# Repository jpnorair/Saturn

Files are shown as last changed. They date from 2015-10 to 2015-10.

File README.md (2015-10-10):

About Saturn I
==============
Saturn I is a board for prototyping low power wireless solutions using OpenTag/DASH7.  It can be used for other purposes as well, but it has a set of features optimized for low-power wireless systems.

Important URLs
==============
 * [Saturn Repository](http://www.github.com/jpnorair/saturn)
 * [OpenTag Repository](http://www.github.com/jpnorair/opentag)
 * [Saturn Wiki on Indigresso](http://www.indigresso.com/wiki/doku.php?id=opentag:board:haystack-saturn-i)
 * [Public Forum on Indigresso](http://www.indigresso.com/forum/)
 * [Pro Support by Haystack](http://www.haystacktechnologies.com)

Licensing
=========
Saturn I is licensed via the GPLv3.  The schematics and board design files are done in DipTrace, and they are available on GitHub.  OpenTag firmware supports the Saturn I, which is also available on GitHub.  Parties interested in a non-GPL version of the Saturn-I design should contact JP Norair to discuss licensing terms.

Building Saturn I Boards
========================
If you decide to build your own Saturn-I boards and resell them, contact JP Norair in order to get a link to your storefront posted on this page.

Otherwise, you can get Saturn-I boards fully produced, on-demand, by [Tempo Automation](http://www.tempoautomation.com).  Tempo has the design on file and is ready to go, just tell them how many you need.  If you want to stuff your own boards and save money (at the expense of time and frustration), there's a ZIP package in the repository ready to go to [OSHPark](http://www.oshpark.com), as well as the necessary assembly files, drawings, and stencil gerbers.  Saturn-I is not designed to be assembled by hobbyists, so be forewarned, as it uses some very small surface mount components.

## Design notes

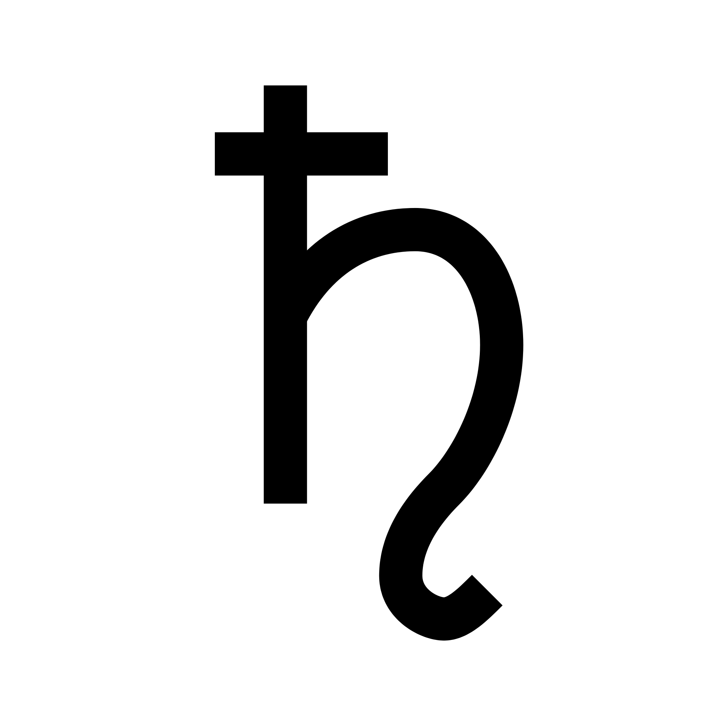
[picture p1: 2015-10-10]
Saturn-I/images/2000px-Saturn_symbol.svg.png

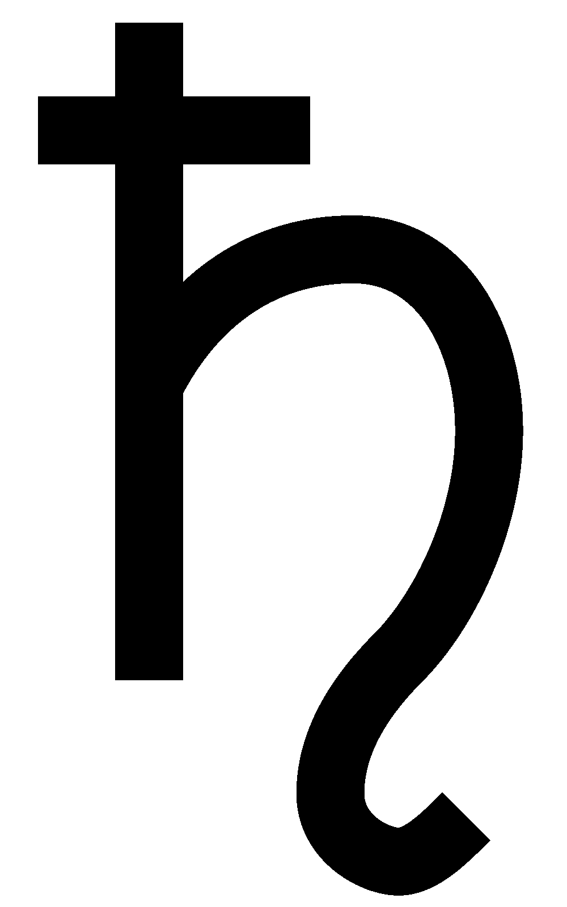
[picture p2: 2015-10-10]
Saturn-I/images/1600px-Saturn_symbol.bmp

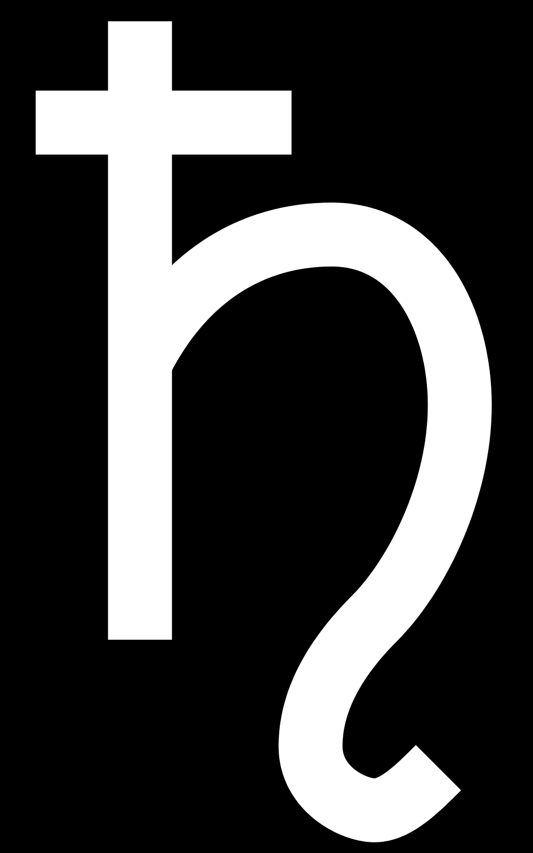
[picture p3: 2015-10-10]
Saturn-I/images/1600px-Saturn_symbol_.png

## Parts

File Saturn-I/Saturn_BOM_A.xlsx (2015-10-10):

Drawing Type | BILL OF MATERIALS
Drawing Title | Saturn I 915 BOM
Revision | 0
Engineer | JP Norair
Release date | 2015-06-15
item | Rev | qty | mfg | part number | alt part number | description (wide tolerance) | references | Comments
1 | 0 | 1 | STMicro | SPIRIT1QTR |  | RF IC | U2
2 | 0 | 1 | STMicro | STM32L151CCU6 |  | MCU, 7x7x0.5 mm | U1
3 | 0 | 1 | STMicro | USBLC6-2P6 |  | SOT-6 USB Protect Diode IC | U3
4 |  | 1 | NXP | NX3L1T384 |  | Leadless Analog Switch | U5
5 |  | 1 | TI | TPS780330220DRV |  | SOT-6 Linear Regulator, 3.3V/2.2V | U4
6 | 0 | 1 | TI | TPS735 |  | SOT-6 Linear Regulator, 3.3V | U6
7 |  | 3 | Panasonic | DB2S20500L |  | SOD-523 (SSMini2) Schottky Diode, If = 200mA | D1, D2, D3
8 |  | 1 | Rohm | SML-P11DTT86 |  | 0402 Orange LED | D4
9 |  | 1 | Rohm | SML-P11MTT86 |  | 0402 Green LED | D5
10 |  | 4 | NXP | BZX884-B5V1,315 |  | SOD-882 Zener Diode, 5.1V | D6, D7, D8, D9
11
12 | 0 | 3 | Murata | GRM155R60J475ME47D |  | 0402 4.7uF X5R decoupling cap | C0, C8, C41
13 | 0 | 9 | Murata | GRM155R71C104KA88D |  | 0402 100nF X7R decoupling cap | C1, C2, C3, C4, C10, C11, C20, C32, C38
14 | 0 | 5 | Murata | GRM155R61A105KE15D |  | 0402 1uF X5R decoupling cap | C5, C9, C31, C39, C40
15 | 0 | 4 | Murata | GRM1555C1H100JA01D |  | 0402 10pF C0G/NP0 crystal caps | C6, C7, C29, C30
16 | 0 | 1 | Murata | GJM1555C1H7R0CB01D |  | 0402 7pF C0G/NP0 RF cap | C21
17 | 0 | 1 | Murata | GJM1555C1H2R4BB01D |  | 0402 2.4pF C0G/NP0 RF cap | C22
18 | 0 | 1 | Murata | GJM1555C1H3R6BB01D |  | 0402 3.6pF C0G/NP0 RF cap | C23
19 | 0 | 1 | Murata | GJM1555C1H2R2BB01D |  | 0402 2.2pF C0G/NP0 RF cap | C24
20 | 0 | 1 | Murata | GJM1555C1H1R5BB01D |  | 0402 1.5pF C0G/NP0 RF cap | C25
21 | 0 | 1 | Murata | GRM1555C1H331JA01D |  | 0402 330pF C0G/NP0 DC blocking cap | C26, C33
22 | 0 | 2 | Murata | GRM1555C1H221JA01D |  | 0402 220pF C0G/NP0 DC blocking cap | C27, C28
23 | 0 | 3 | Murata | GRM1555C1H331JA01D |  | 0402 330pF C0G/NP0 decoupling cap | C33, C37
24 | 0 | 2 | N/A | N/A |  | 0402 No Stuff | C34, C35 | No Stuff
25 | 0 | 2 | Murata | GRM155R71E103KA01D |  | 0402 10nF X7F decoupling cap | C36, C42
26 | 0 | 1 | Murata | LQG15HSR10J02D |  | 0402 100nH inductor | L20
27 | 0 | 1 | Murata | LQG15HS3N6S02D |  | 0402 3.6 nH RF inductor | L21
28 | 0 | 1 | Murata | LQG15HS5N1S02D |  | 0402 5.1 nH RF inductor | L22
29 | 0 | 1 | Panasonic | ERJ-2GE0R00X |  | 0402 Jumper | L23
30 | 0 | 1 | Murata | LQG15HS15NJ02D |  | 0402 15 nH RF inductor | L24, L26
31 | 0 | 1 | Murata | LQG15HS18NJ02D |  | 0402 18 nH RF inductor | L25
32 | 0 | 1 | Murata | LQM21FN100M80L |  | 0805 10uH shielded power inductor | L27
33 | 0 | 1 | Murata | LQG15HS27NJ02D |  | 0402 27nH power inductor | L28
33 | 0 | 1 | N/A |  |  | 0402 No Stuff | L29
34 | 0 | 1 | Abracon | ABS07-32.768KHZ-T |  | 32768 Hz, SMD-2, ±20ppm | X1
35 | 0 | 1 | Abracon | ABM11-48.000MHZ-D2X-T3 |  | 48MHz, SMD-4, ±20ppm | X20
36 | 0 | 1 | Yageo | RC0402JR-07100KL |  | 0402 100kΩ 5% resistor RST pullup | R1, R6
37 | 0 | 2 | Vishay Dale | CRCW04022M49FKED |  | 0402 2.49MΩ 1% resistor | R2, R3
38 | 0 | 1 | Yageo | RC0402JR-071KRL |  | 0402 1kΩ 5% resistor | R4
39 | 0 | 1 | Yageo | RC0402JR-07330RL |  | 0402 330Ω 5% resistor | R5
40 | 0 | 1 | Panasonic | ERJ-2GE0R00X |  | 0402 Jumper | R20
41 | 0 | 1 | N/A | N/A |  | 0402 No Stuff | R21
42 | 0 | 2 | Sullins | PPTC081LFBN-RC |  | 8x1 vertical-through-hole 2.54mm female header | J1, J3 | SUPPLY WITH KIT, BUT DO NOT STUFF
43 | 0 | 1 | Sullins | PPTC061LFBN-RC |  | 6x1 vertical-through-hole 2.54mm female header | J2 | SUPPLY WITH KIT, BUT DO NOT STUFF
44 | 0 | 2 | N/A | N/A |  | 2x1 vertical-through-hole 2.54mm male header | J3a, J3b | No Stuff
45 | 0 | 1 | Sullins | PPTC101LFBN-RC |  | 10x1 vertical-through-hole 2.54mm female header | J4 | SUPPLY WITH KIT, BUT DO NOT STUFF
46 | 0 | 1 | FCI | 68602-120HLF |  | 10x2 vertical-through-hole 2.54mm male header | J5 | SUPPLY WITH KIT, BUT DO NOT STUFF
47 | 0 | 1 | MPD | BU2450SM-JJ-GTR |  | SMT 2450 Coin Cell Battery holder | B1
48 | 0 | 1 | Panasonic | BSG CR2450 |  | 2450 Coin Cell Battery | B1.1 | SUPPLY WITH KIT, BUT DO NOT STUFF
49 | 0 | 1 | N/A | ESP-06 |  | ESP-06 WiFi module | CN1 | No Stuff
50 | 0 | 1 | Mill Max | 896-43-005-00-100001 |  | SMT USB Mini-A Connector | CN2
51 | 0 | 1 | Taoglas | EMPCB.SMAFSTJ.B.HT |  | SMA Board Edge connector | CN5 | Optional, only needed for screw antenna
52 | 0 | 2 | C&K Components | KMR442G |  | SMT Push Button Switch | S1, S2
Total Parts Used: |  | 83
Total Parts Cost:
